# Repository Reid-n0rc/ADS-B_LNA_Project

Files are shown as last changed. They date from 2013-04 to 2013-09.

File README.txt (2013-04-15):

The filter/LNA project is designed to improve the ADS-B Reception of a RTL-SDR USB Dongle.  More on operation of the dongle and reception of ADS-B can be found at <http://www.reddit.com/r/rtlsdr>.

There are three elements extrenal to the software/sdr that this project emcompasses: the antenna, frontend filter, and LNA.  

ANTENNA:
----------
Any antenna that covers 1090MHz can be used for this purpose.  I am using a design found here: <http://www.sprut.de/electronic/pic/projekte/adsb/adsb_en.html#antenne>.

FILTER:
----------
Files for the filter design are contained the in the Filter directory.  There are two versions of the filter layout.  The "standard" filter, and filter_slant.  Filter_slant is the same as filter, just adjusted so the connectors are in a line in the X/Y Plane.  This will allows for a narrower PCB, and keeps any forces in the same direction, ie. doesn't try to pull the connector off to the side.  This is good for an antenna mounted design.

The main filter directory contains the .dxf files for the filter design.  You can use a free dxf viewer to see the filter and print it.  be sure that if you print the file to etch a filter, that it is 1:1 scale, otherwise the frequency of operation will be shifted.

Eagle specific files are contained in the eagle specific sub-directory.  The script (.scr) files can be used to generate the filter in any board layout.

If you're sending out the PCB for fab, make sure there is no solder mask over the PCB area, as this can affect the filter's frequency response.  You can take the .brd files and send them directly to OSH Park <http://oshpark.com/> for fabrication.

Filter performance can be seen in the Test_Data sub-directory.

LNA:
----------
The LNA design is still in the works, but is based on the design shown here: <http://www.lll.lu/~edward/edward/adsb/preamp/ADSBpremap.html> and modified as per the instructions of Dr. Ken Filardo, KA0THK

CC-BY-SA N0RC, 2013.

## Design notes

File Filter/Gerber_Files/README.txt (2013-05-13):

Gerber Files formatted for ITEAD Studio http://blog.iteadstudio.com/

*.TXT -- Drill data
*.GML -- Edge milling
*.do  -- Drill & Board outline
*.GBP -- Padmask bottom
*.GTP -- Padmask top
*.GBS -- Solder mask bottom
*.GTS -- Solder mask top
*.GBO -- Silk bottom
*.GTO -- Silk top
*.GBL -- Bottom copper
*.GTL -- Top copper

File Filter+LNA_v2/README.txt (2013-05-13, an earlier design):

Schematic and Layout hosted at: http://upverter.com/RTLSDR_Addons/fb2911b6e6312c93/Filter--LNA-ver-2/

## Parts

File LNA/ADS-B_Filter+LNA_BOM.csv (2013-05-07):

Digi-Key Part Number | Manufacturer | Manufacturer Part Number | Customer Reference | Quantity 1 | Quantity 2 | Quantity 3 | Description | Comments | RoHS Status | Lead Free Status | REACH Status
BFP 420 H6327CT-ND | INFINEON TECHNOLOGIES (VA) | BFP 420 H6327 | U1 | 1 | 0 | 0 | TRANS RF NPN 25GHZ 4.5V SOT343 | Alternate Packaging Exists | RoHS Compliant | Lead free | Not Available
RMCF0805FT22K0CT-ND | STACKPOLE ELECTRONICS INC (VA) | RMCF0805FT22K0 | R1 | 1 | 0 | 0 | RES 22K OHM 1/8W 1% 0805 | Alternate Packaging Exists | RoHS Compliant | Lead free | Unaffected Aug-2011
RMCF0805FT604RCT-ND | STACKPOLE ELECTRONICS INC (VA) | RMCF0805FT604R | R2 | 1 | 0 | 0 | RES 604 OHM 1/8W 1% 0805 | Alternate Packaging Exists | RoHS Compliant | Lead free | Unaffected Aug-2011
712-1394-1-ND | JOHANSON TECHNOLOGY INC (VA) | 251R15S101JV4E | C1,C2 | 2 | 0 | 0 | CAP CER 100PF 250V 5% NP0 0805 | Alternate Packaging Exists | RoHS Compliant | Lead free | Unaffected Jul-2011

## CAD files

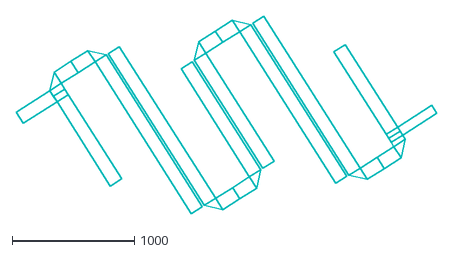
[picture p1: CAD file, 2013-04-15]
Filter/dxf_files/filter_slant.dxf
3436.4 x 1612.3

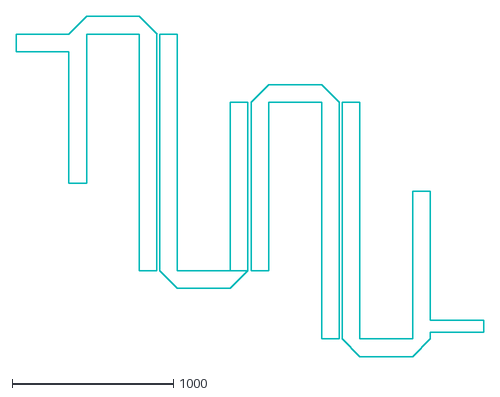
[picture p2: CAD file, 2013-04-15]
Filter/dxf_files/filter.dxf
2897.5 x 2107.3

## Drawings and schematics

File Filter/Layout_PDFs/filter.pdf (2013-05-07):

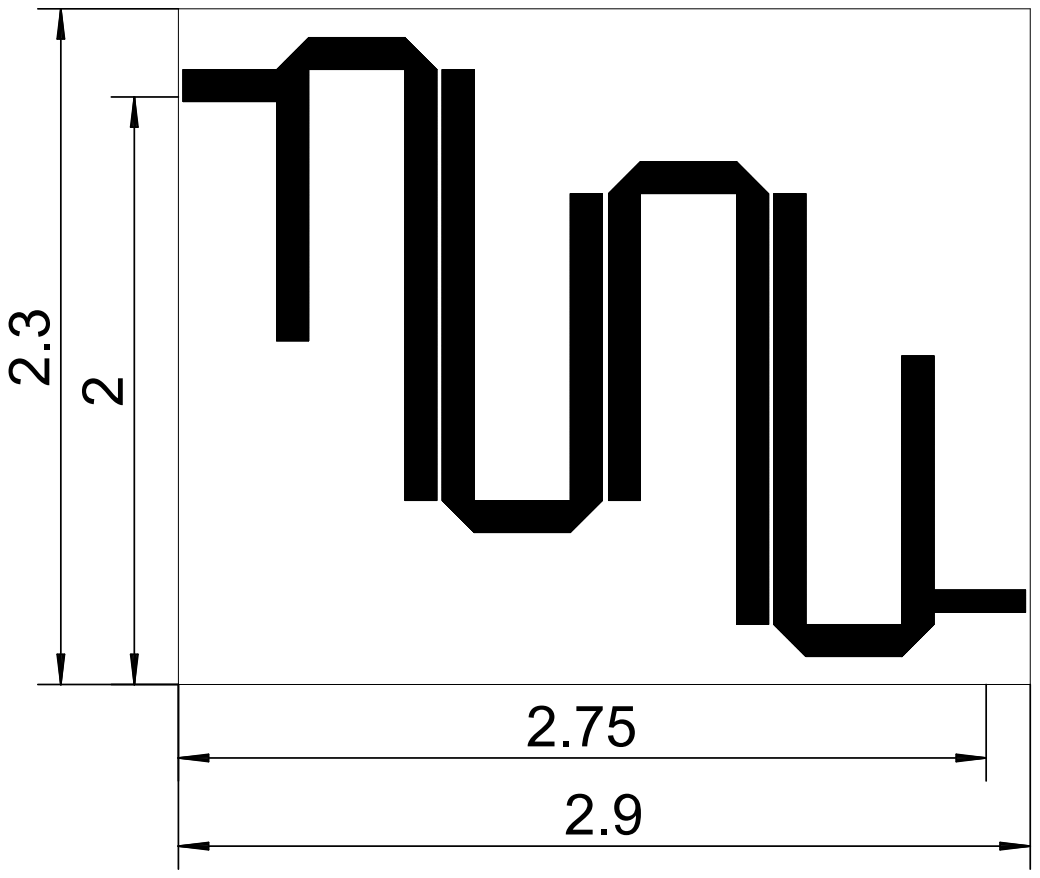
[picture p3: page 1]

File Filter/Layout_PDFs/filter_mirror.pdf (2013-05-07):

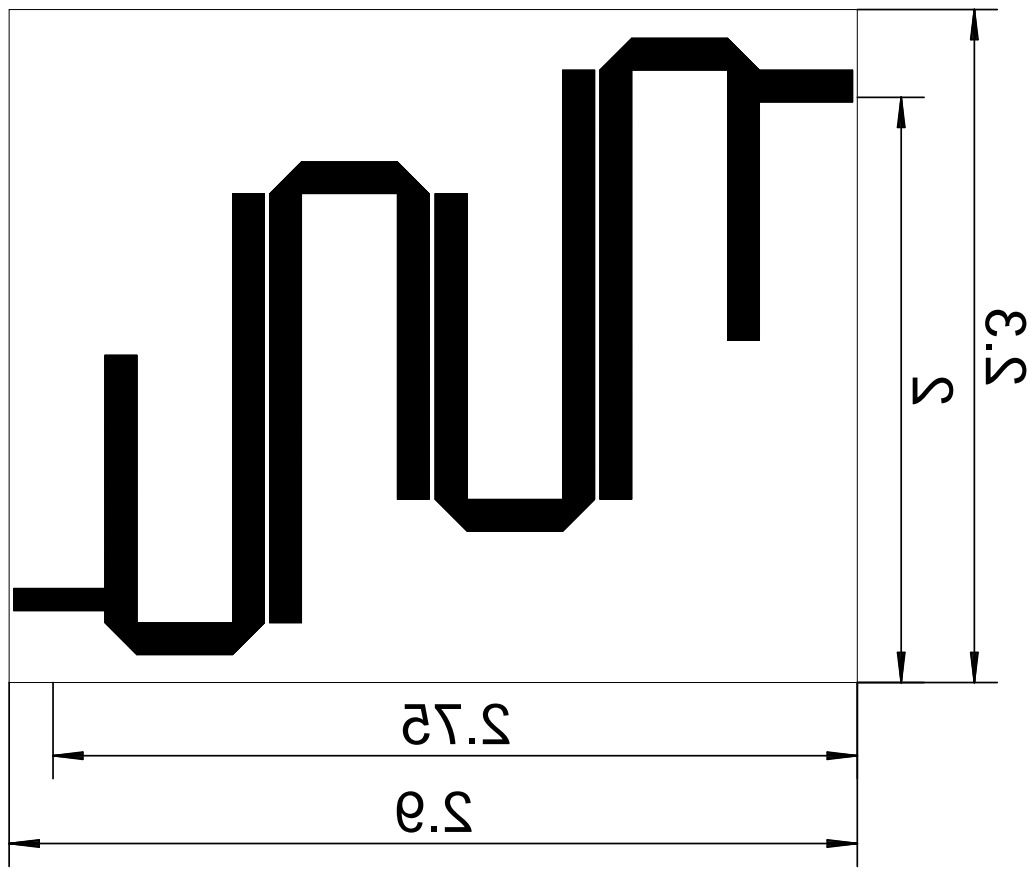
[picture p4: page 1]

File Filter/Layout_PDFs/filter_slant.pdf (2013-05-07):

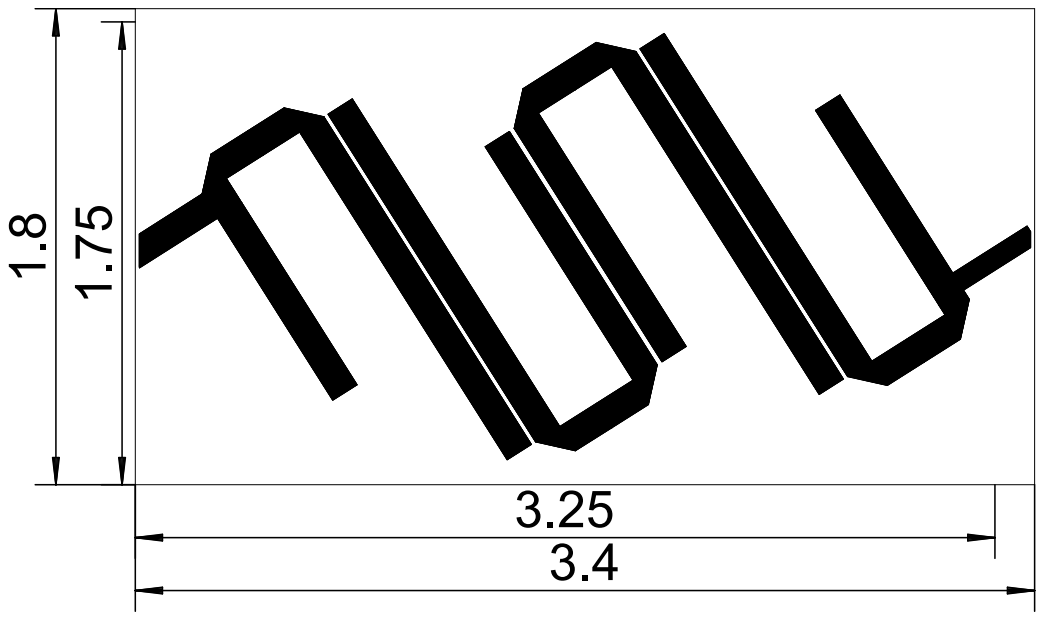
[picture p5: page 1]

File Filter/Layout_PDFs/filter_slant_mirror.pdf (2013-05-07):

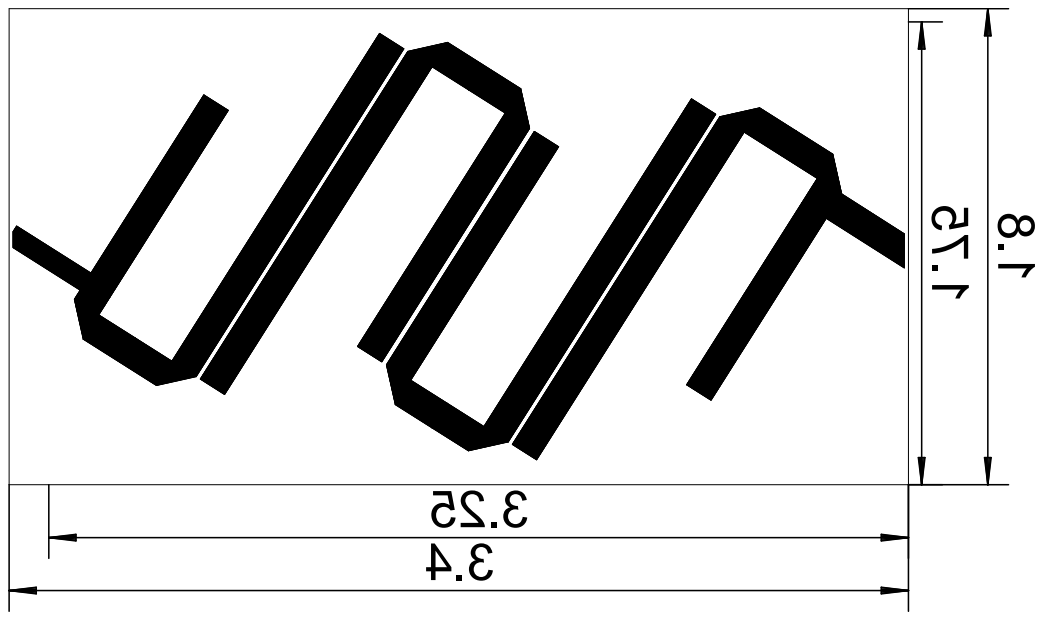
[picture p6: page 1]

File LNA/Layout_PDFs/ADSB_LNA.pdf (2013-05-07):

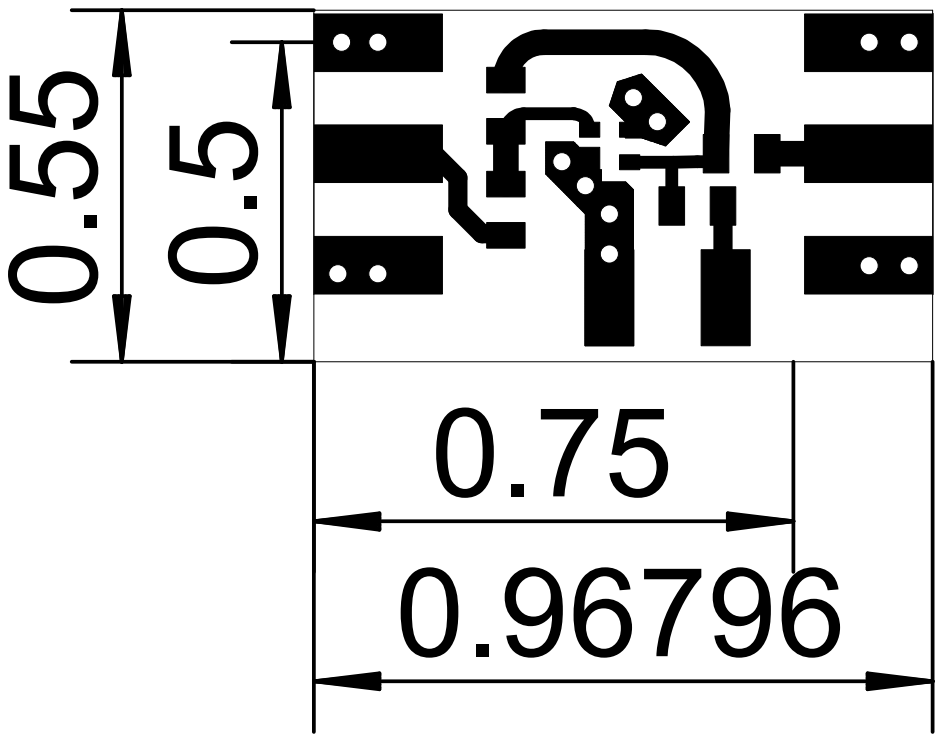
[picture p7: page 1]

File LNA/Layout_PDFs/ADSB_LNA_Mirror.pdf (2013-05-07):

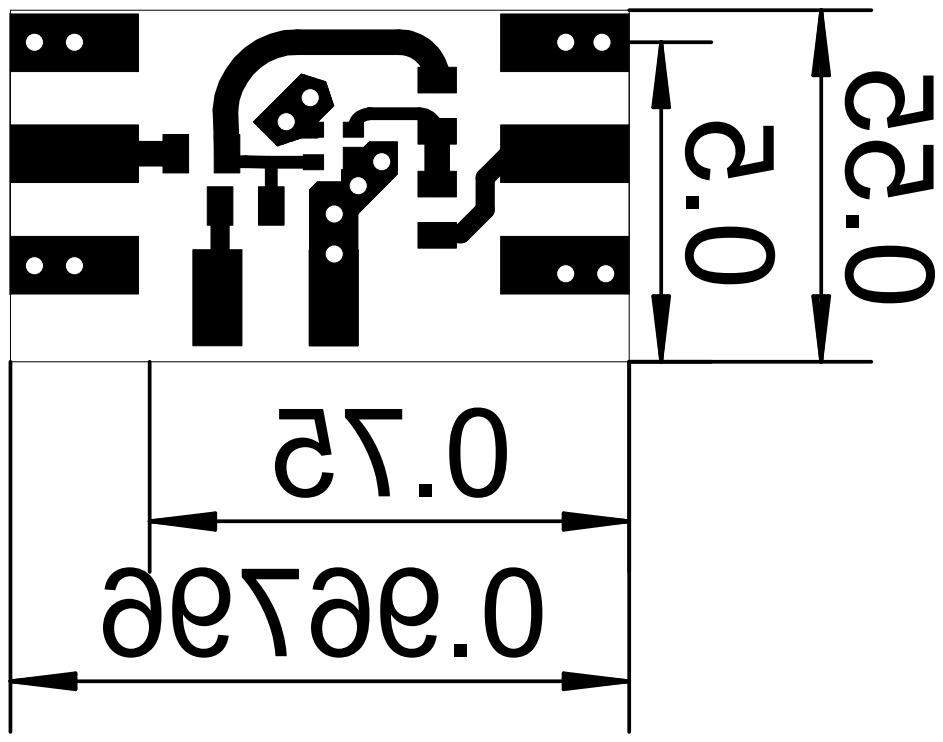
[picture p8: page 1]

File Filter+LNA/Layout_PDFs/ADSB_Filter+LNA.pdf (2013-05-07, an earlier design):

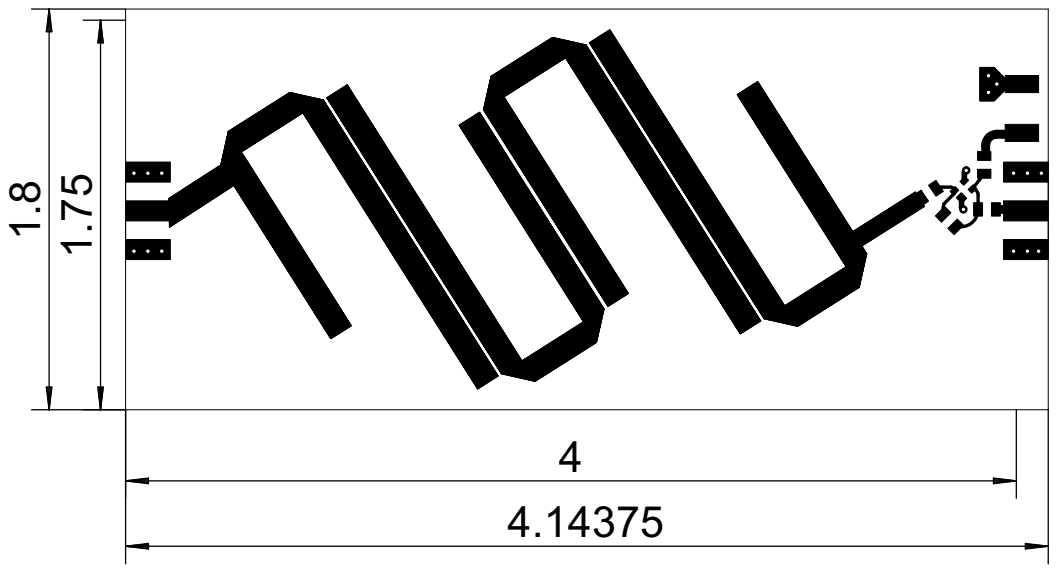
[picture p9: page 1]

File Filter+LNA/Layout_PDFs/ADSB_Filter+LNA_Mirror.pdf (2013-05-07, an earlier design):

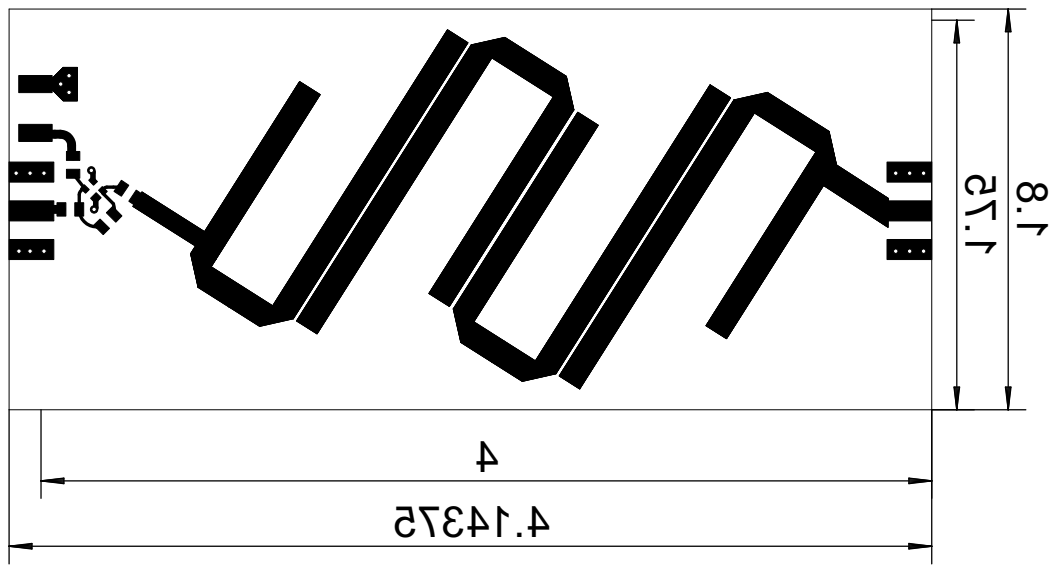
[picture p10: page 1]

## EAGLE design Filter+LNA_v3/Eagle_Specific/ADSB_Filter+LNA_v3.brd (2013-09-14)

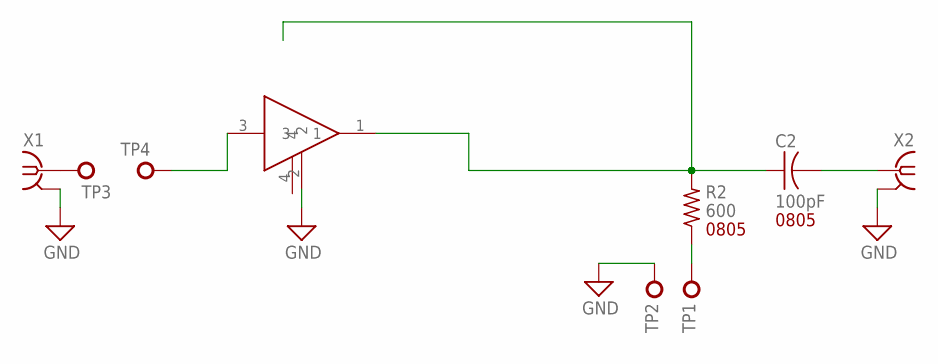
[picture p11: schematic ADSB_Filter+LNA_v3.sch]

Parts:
C2: 100pF; 0805
R2: 600; 0805
TP1, TP2: TEST_POINTS76_150; SMD_76_150
TP3, TP4: TEST_POINTS8_8; SMD_8_8
U$1: SPF-5043Z; SOT-343_2&4_FUSED
X1, X2: SMA-142-0701-801/806; J502-ND-142-0701-801/806

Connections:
1: TP3.1, X1.1
10: TP4.1, U$1.3
GND: TP2.1, U$1.2, X1.G@1 (GND), X1.G@2 (GND), X1.G@3 (GND), X1.G@4 (GND), X2.G@1 (GND), X2.G@2 (GND), X2.G@3 (GND), X2.G@4 (GND)
unnamed: C2.1, R2.2, U$1.1
unnamed: R2.1, TP1.1
unnamed: C2.2, X2.1

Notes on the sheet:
0805

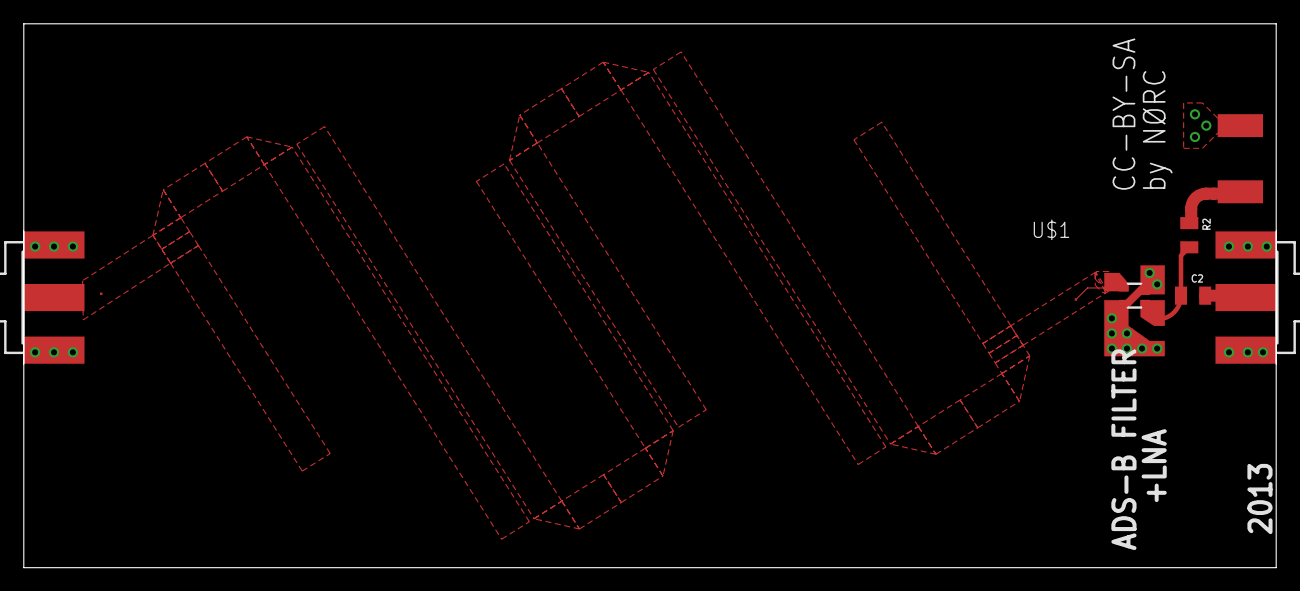
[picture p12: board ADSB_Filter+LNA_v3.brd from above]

Board: 2 copper layers, 105.3 x 45.7 mm, 9 parts (0 on the bottom side), 6 nets.

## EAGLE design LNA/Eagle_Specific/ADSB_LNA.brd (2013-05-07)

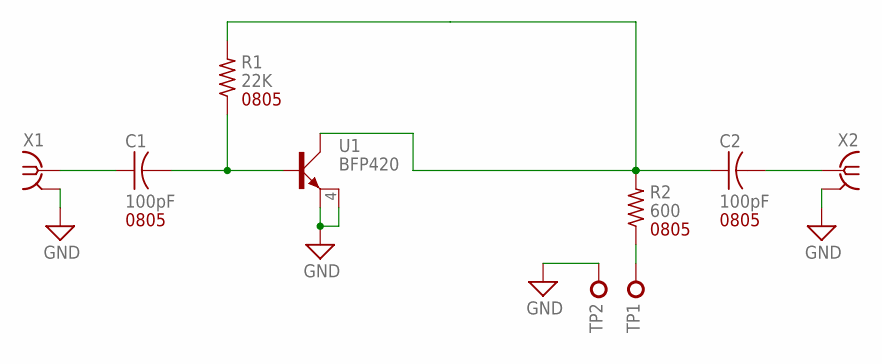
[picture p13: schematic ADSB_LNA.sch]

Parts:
C1, C2: 100pF; 0805
R1: 22K; 0805
R2: 600; 0805
TP1, TP2: TEST_POINTS76_150; SMD_76_150
U1: BFP420; SOT343_INFINEON
X1, X2: SMA-142-0701-801/806; J502-ND-142-0701-801/806

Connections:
GND: TP2.1, U1.2 (E1), U1.4 (E2), X1.G@1 (GND), X1.G@2 (GND), X1.G@3 (GND), X1.G@4 (GND), X2.G@1 (GND), X2.G@2 (GND), X2.G@3 (GND), X2.G@4 (GND)
unnamed: C1.1, X1.1
unnamed: C1.2, R1.1, U1.1 (B)
unnamed: C2.1, R1.2, R2.2, U1.3 (C)
unnamed: R2.1, TP1.1
unnamed: C2.2, X2.1

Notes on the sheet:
0805

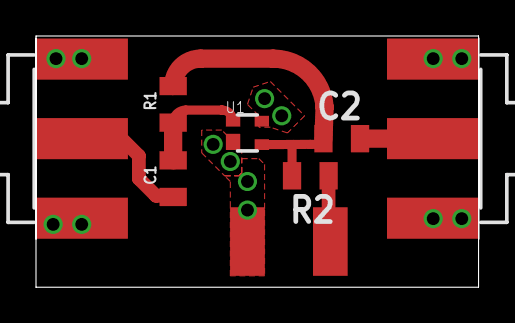
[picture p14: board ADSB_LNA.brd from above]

Board: 2 copper layers, 24.6 x 14.0 mm, 9 parts (0 on the bottom side), 6 nets.

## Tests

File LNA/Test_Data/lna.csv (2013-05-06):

!CSV A.01.01
!Agilent Technologies | N5222A | MY51421306 | A.09.85.08
!Agilent N5222A: A.09.85.08
!Date: Monday | May 06 | 2013 14:40:15
!Source: Standard
BEGIN CH1_DATA
Freq(Hz) | S11(DB) | S11(DEG) | S12(DB) | S12(DEG) | S21(DB) | S21(DEG) | S22(DB) | S22(DEG)
100000000 | -2.3714077 | -20.564632 | -34.585258 | 44.922333 | 19.526291 | 166.91188 | -2.7281463 | -23.068605
101100000 | -2.3864727 | -20.790798 | -34.337738 | 47.544777 | 19.532619 | 166.57567 | -2.762377 | -23.360682
102200000 | -2.3924224 | -21.108166 | -34.348621 | 48.566689 | 19.536646 | 166.28009 | -2.7615926 | -23.535294
103300000 | -2.3785989 | -21.298872 | -34.327133 | 45.878651 | 19.535692 | 165.9761 | -2.774039 | -23.847036
104400000 | -2.3900769 | -21.600771 | -33.879608 | 46.08065 | 19.535213 | 165.62776 | -2.763864 | -24.100019
105500000 | -2.3968439 | -21.897554 | -34.136211 | 44.933819 | 19.524317 | 165.29005 | -2.7890143 | -24.24457
106600000 | -2.4146693 | -22.120619 | -33.883015 | 50.600067 | 19.522711 | 165.00093 | -2.7898824 | -24.672218
107700000 | -2.412199 | -22.400932 | -33.547382 | 46.628159 | 19.520348 | 164.64342 | -2.8339179 | -24.957397
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

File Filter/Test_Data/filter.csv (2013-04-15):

!CSV A.01.01
!Agilent Technologies | N5222A | MY51421306 | A.09.85.08
!Agilent N5222A: A.09.85.08
!Date: Monday | April 15 | 2013 09:25:11
!Source: Standard
BEGIN CH2_DATA
Freq(Hz) | S21(DB) | S21(DEG)
80000000 | -65.856056 | 69.004684
80060000 | -65.88047 | 66.368774
80120000 | -66.052284 | 68.902512
80180000 | -66.303329 | 67.735489
80240000 | -65.638145 | 63.228352
80300000 | -65.670219 | 67.069511
80360000 | -65.56926 | 66.235321
80420000 | -66.021538 | 65.253716
80480000 | -65.812706 | 69.393143
80540000 | -65.902206 | 66.734428
80600000 | -65.556137 | 63.802574
80660000 | -65.479347 | 64.235443
80720000 | -65.992134 | 68.548759
80780000 | -65.52005 | 63.053146
80840000 | -65.155296 | 63.630535
80900000 | -65.287392 | 68.208496
80960000 | -65.451988 | 63.586124
81020000 | -65.750534 | 65.813118
81080000 | -65.410843 | 70.103485
81140000 | -65.703239 | 65.121887
81200000 | -65.582832 | 67.655945
81260000 | -65.310776 | 63.984619
81320000 | -65.578285 | 69.814377
81380000 | -65.72316 | 66.584518
81440000 | -65.849419 | 66.10685
81500000 | -65.406319 | 64.533775
81560000 | -65.963951 | 67.891693
81620000 | -65.736664 | 65.379005
81680000 | -65.140923 | 64.377129
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

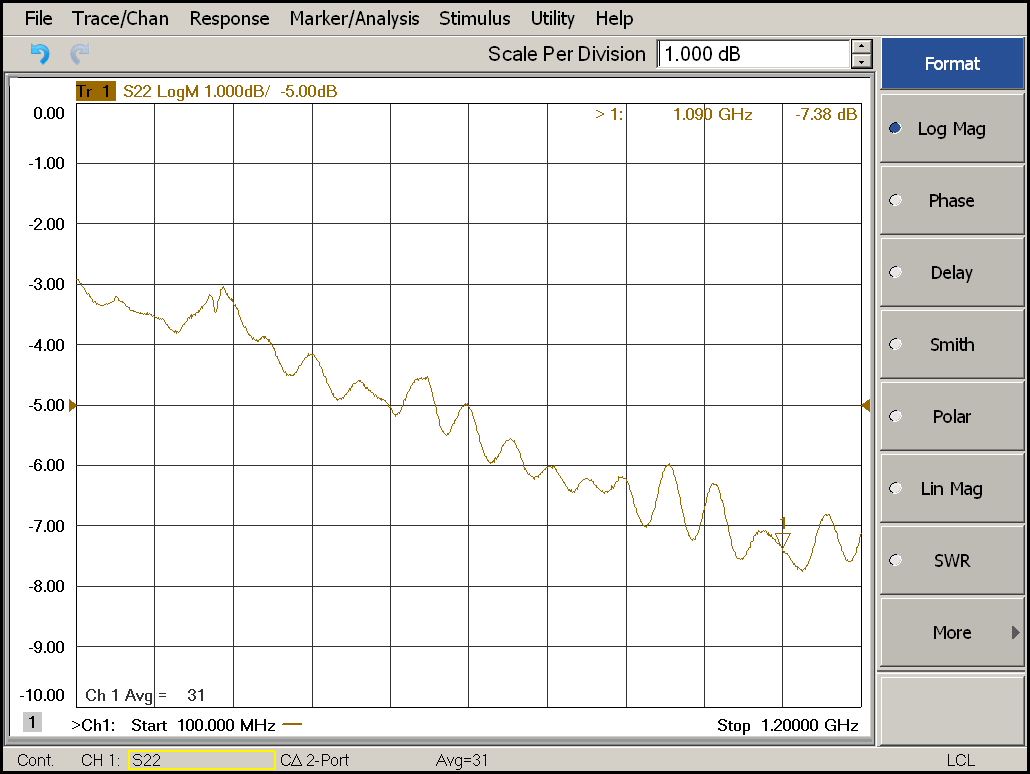
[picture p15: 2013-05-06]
LNA/Test_Data/ADSB_LNA_v2_s22.png

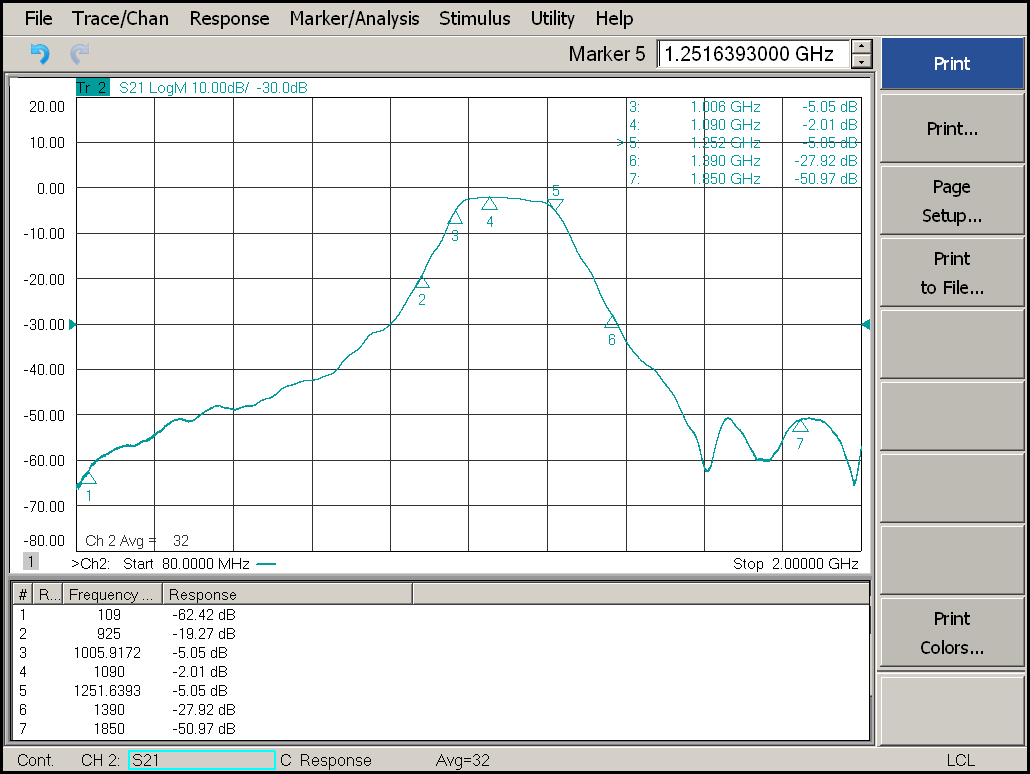
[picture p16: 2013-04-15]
Filter/Test_Data/filter.png

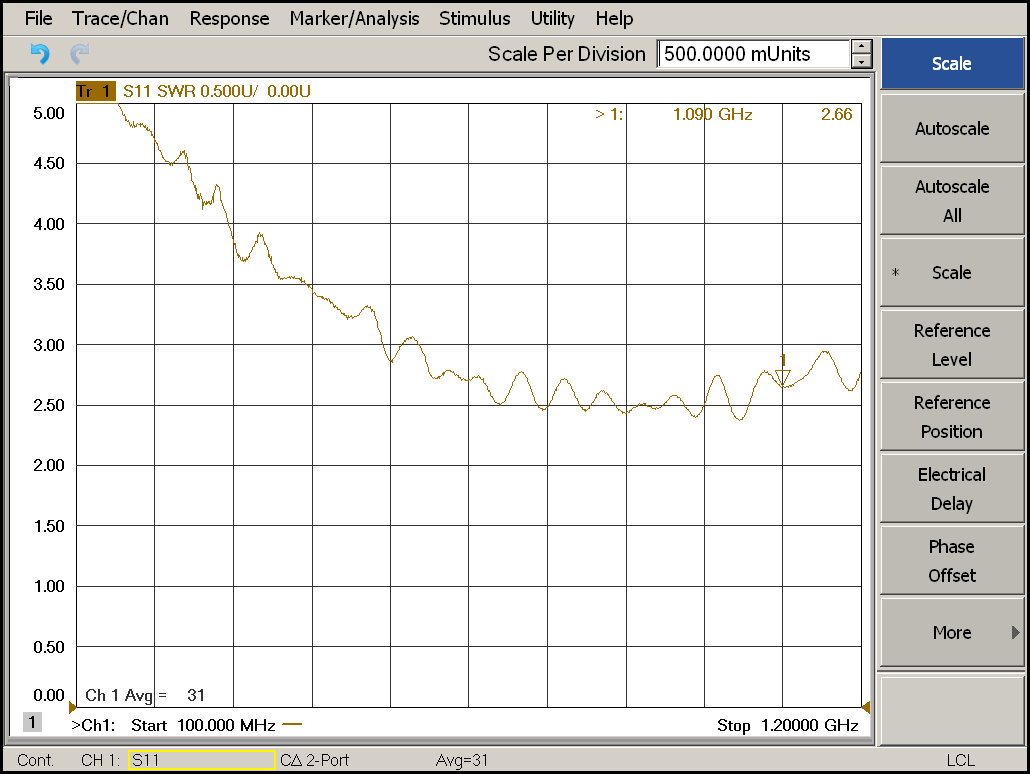
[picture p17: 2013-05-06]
LNA/Test_Data/ADSB_LNA_v2_s11_swr.png

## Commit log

2013-04-15 Initial commit of filter design
    [filter.brd, filter_slant.brd]
2013-04-15 Reorganized dir, added .dxf files, test data
    [filter.brd, filter.csv, filter.dxf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]
2013-05-06 Added files on the Amp alone
    [ADSB_AMP_V2.brd, ADSB_AMP_V2.sch]
2013-05-06 Added test data
    [lna.csv]
2013-05-07 Added Filter+LNA PCB
    [ADSB_AMP_V3.brd, ADSB_AMP_V3.sch]
2013-05-07 Updated Layout
    [ADSB_AMP_V3.brd]
2013-05-07 Changed file names and added Layouts as PDFs
    Changed file names to better describe what what is in them. Added
    layout as B&W PDF files with dimensions to allow for etching PCB with
    toner transfer or other process.
    [ADSB_Filter+LNA.brd, ADSB_Filter+LNA.sch, ADSB_LNA.brd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]
2013-05-07 Moved Filter&LNA Layout PDFs to their own folder
2013-05-07 Change width of copper pour from 0 to 1
    Copper pour with width 0 times out the OSH Park service. Changed to 1
    as per @laen
    [ADSB_Filter+LNA.brd, filter_slant.brd]
2013-05-07 Minor changes to Filter+LNA Layout
    [ADSB_Filter+LNA.brd, ADSB_Filter+LNA.sch]
2013-05-07 Added license info to all layouts
    [ADSB_Filter+LNA.brd, ADSB_LNA.brd, filter.brd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]
2013-05-07 Added BOM for LNA. Importable into Digi-Key
    [ADS-B_Filter+LNA_BOM.csv]
2013-05-07 Updated Filter+LNA gerber. Removed old filename.
2013-05-13 README for Gerber Extensions
    Added README for each Gerber Files directory explaining what each file
    type corresponds to.
2013-05-13 Removed dimm from layouts
    [filter.brd, filter_slant.brd]
2013-05-13 replaced gerbers for ones formatted for ITEAD
    [ADSB_Filter+LNA.GBL, ADSB_Filter+LNA.GBO, ADSB_Filter+LNA.GBP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]
2013-05-13 Added *.sch to be compatible with Upverter
    [filter.sch, filter_slant.sch]
2013-05-13 Added Filter+LNA_v2 - Not finished
    Added Filter+LNA_v2. Schematic and layout hosted at Upverter:
    http://upverter.com/RTLSDR_Addons/fb2911b6e6312c93/Filter--LNA-ver-2/
    Gerbers here are not finished.
    [layers.cfg]
2013-09-14 Finished Layout with SPF5043Z
    [ADSB_Filter+LNA_v3.brd, ADSB_Filter+LNA_v3.sch]
